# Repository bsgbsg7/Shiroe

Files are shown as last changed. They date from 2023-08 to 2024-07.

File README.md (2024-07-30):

# Design of Electronic Perpetual Calendar Based on ESP32 

## 功能展示

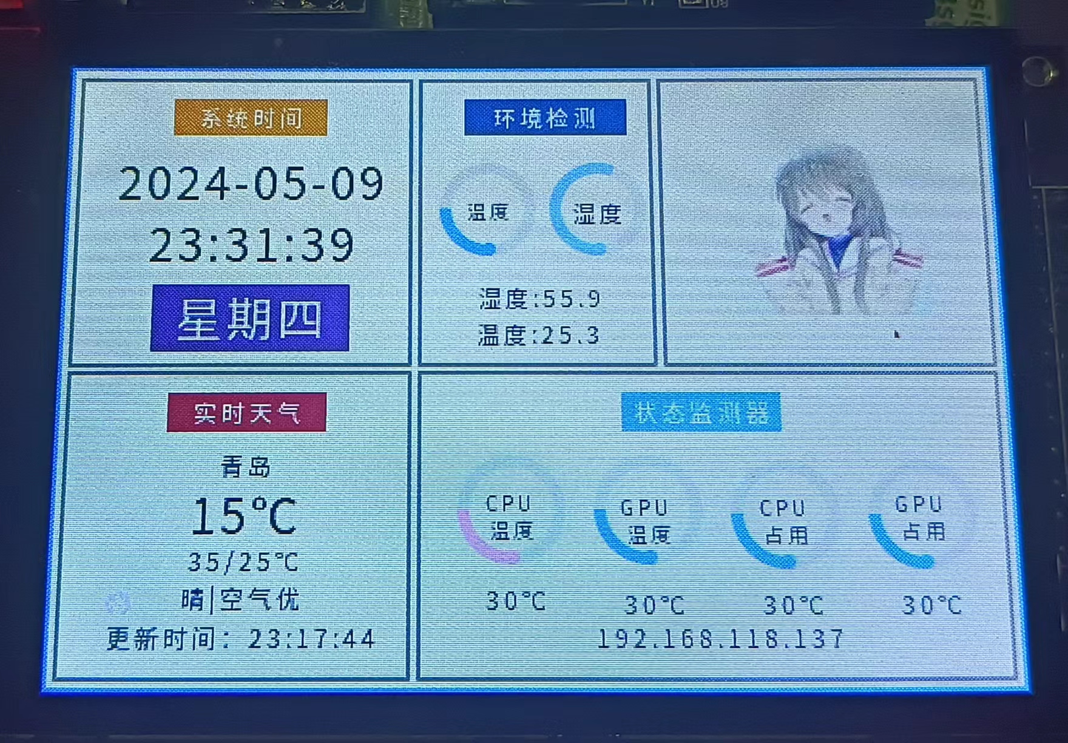
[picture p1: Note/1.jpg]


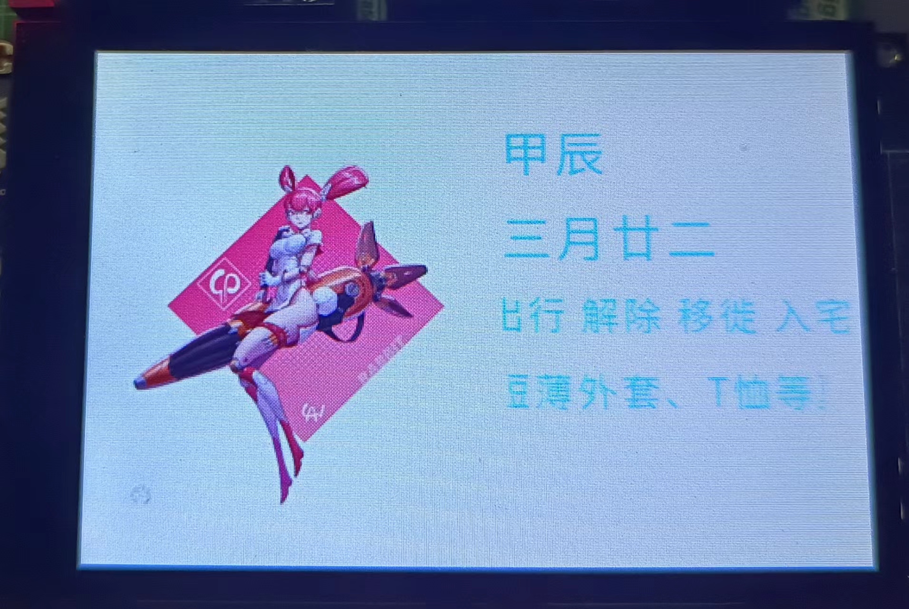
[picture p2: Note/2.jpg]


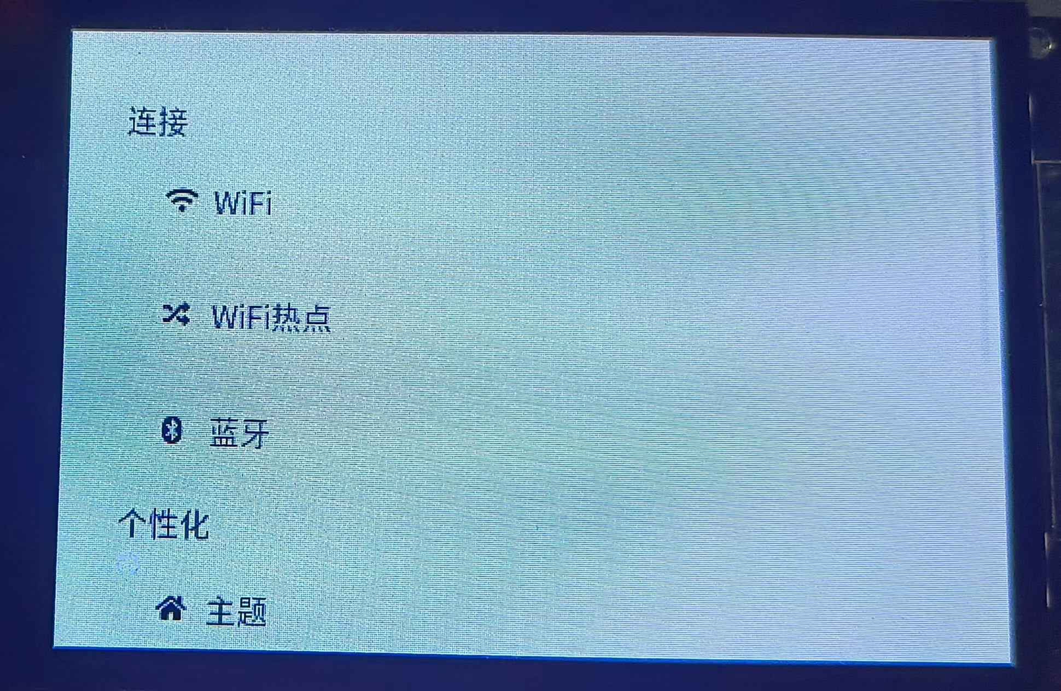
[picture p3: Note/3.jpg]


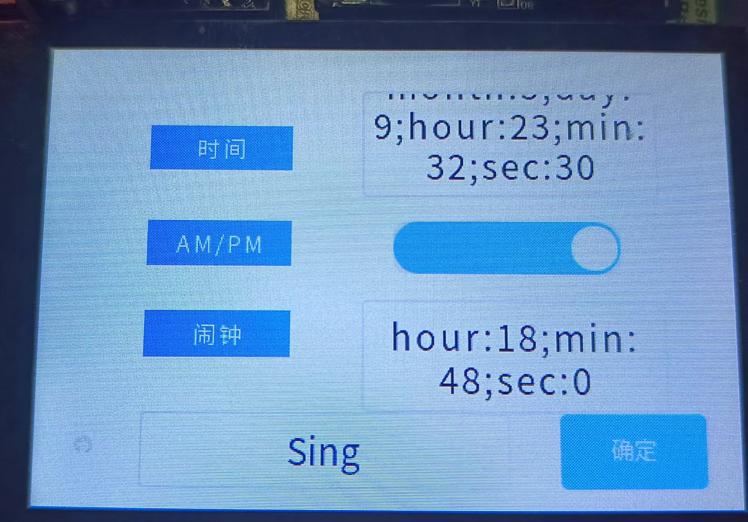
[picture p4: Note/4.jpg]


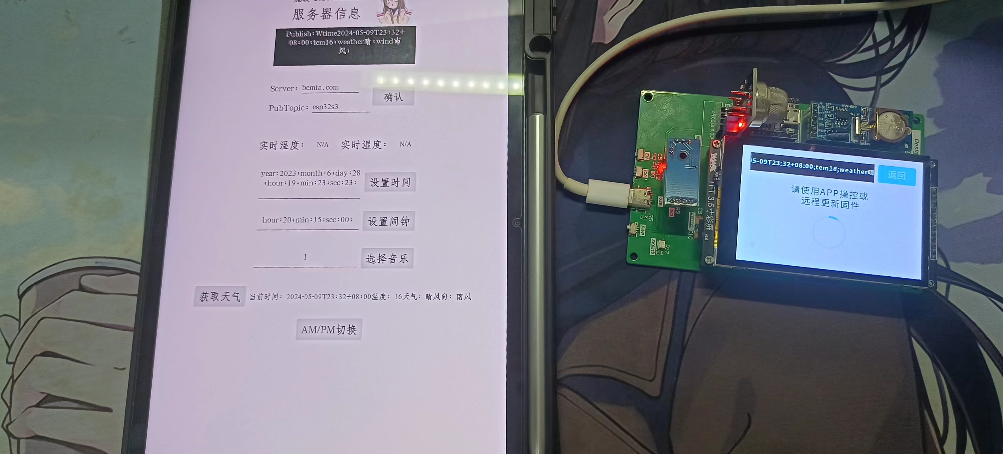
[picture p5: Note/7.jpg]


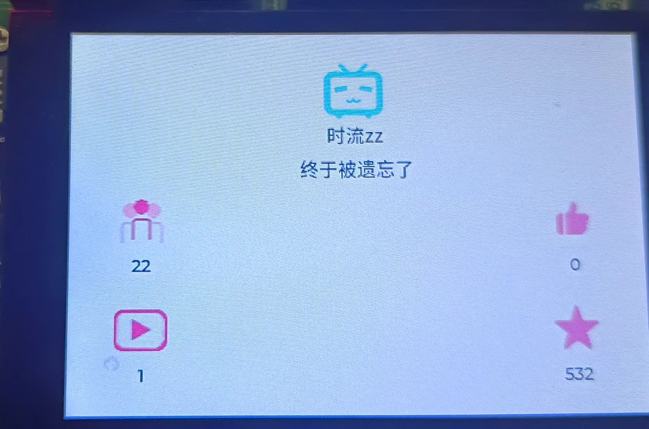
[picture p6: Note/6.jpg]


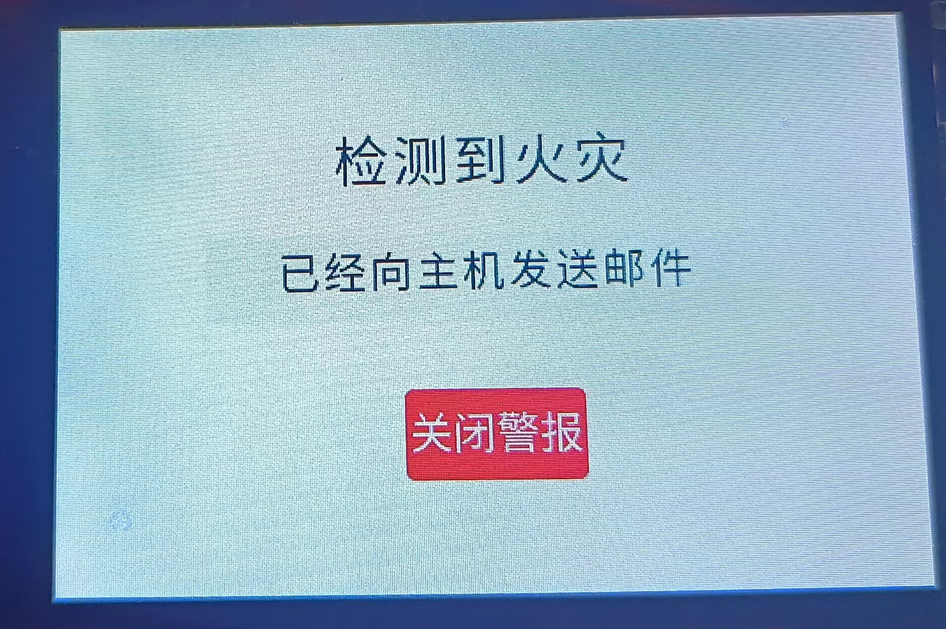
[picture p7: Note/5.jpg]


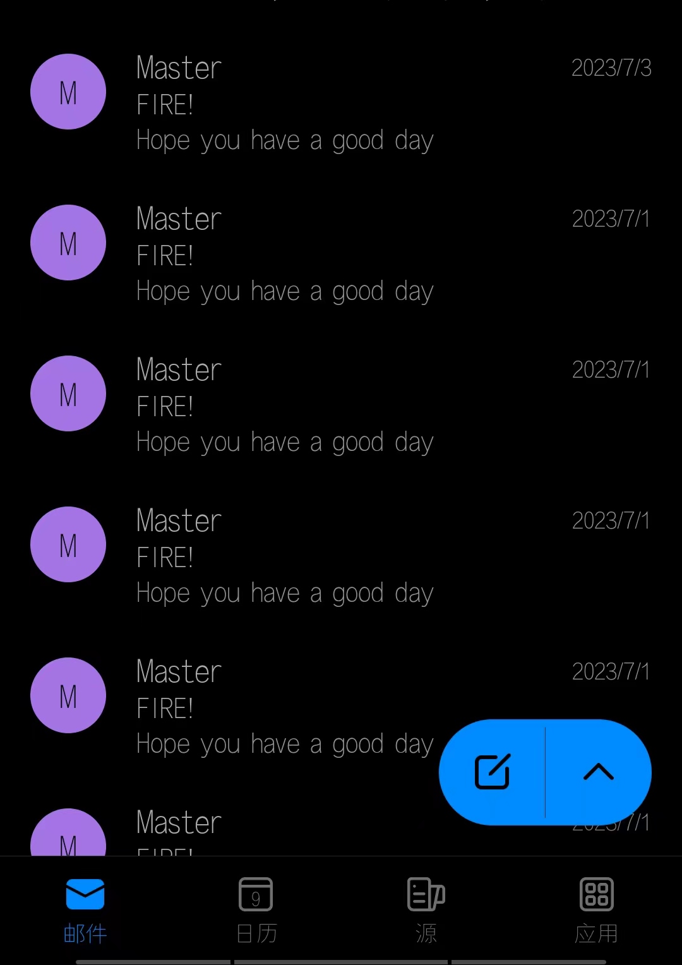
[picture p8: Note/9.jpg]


## 一、已实现的功能

>- 当前的年、月、日、时、分、秒显示
>- 设置年、月、日、时、分、秒
>- AM、 PM 设置与显示
>- 农历年月日、二十四节气显示
>- 闹钟时间设置，闹钟时间到进行声光报警提示
>- 温湿度检测与显示
>- 闹钟音乐选择（采用 TF 卡或录音芯片存储音乐数据）
>- 手机通过蓝牙或 WiFi 网络连接该万年历，通过手机 APP 可以完成基本功能中的所有设置功能
>- 通过编写 Android 手机程序获得网上天气预报数据，并将该数据通过蓝牙或WiFi 网络传递给音乐万年历，万年历可以完成天气信息显示
>- 火灾检测与报警，采用声光报警和发送邮件的形式提醒
>- 电脑状态监测，实时监控电脑CPU、GPU状态
>- Bilibili用户数据实时显示
>- 系统菜单界面

## 二、 硬件设计

### （1）原理图设计及其各模块简介

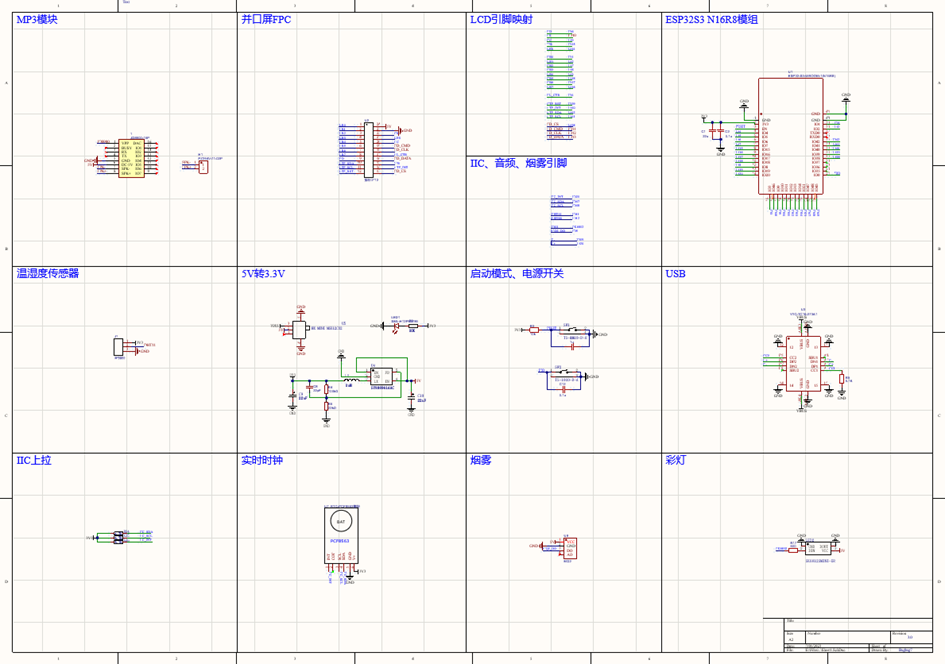
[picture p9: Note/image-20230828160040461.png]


**主控：** ESP32-S3-WROOM-1(N16R8)模组，内置2.4GHz WiFi以及低功耗蓝牙，双核 32 位 LX7 微处理器，高达 240 MHz 的时钟频率， 384 KB ROM ，512 KB SRAM ，16MB Flash，8MB PSRAM。

**电源转换：**SY8089A1AAC同步降压DC/DC稳压器，能够提供高达2A的输出电流，可以在2.5V到5.5V的宽输入电压范围内工作，输出电压纹波小，外接电感小。

**显示屏：**ST7789V电容触摸屏，采用8位并口模式通信。

**时钟芯片：** PCF8563模块，支持IIC通信，配有CR1220备用电池以及二极管保证任何时候都有一个供电。

**烟雾检测模块：**MQ2模块。

**音乐模块：**JQ8900模块，采用特有的一线控制模式，5V供电，通过导线外接8W 0.5Ω的喇叭。

**温湿度模块：**DHT11模块。

**彩灯：**SK6812RGB彩灯。

**USB**：Type-C USB。

### （2）印制板图设计

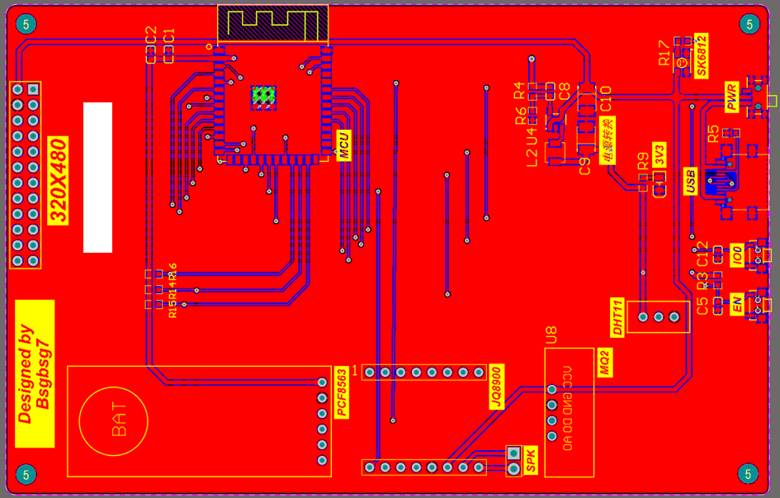
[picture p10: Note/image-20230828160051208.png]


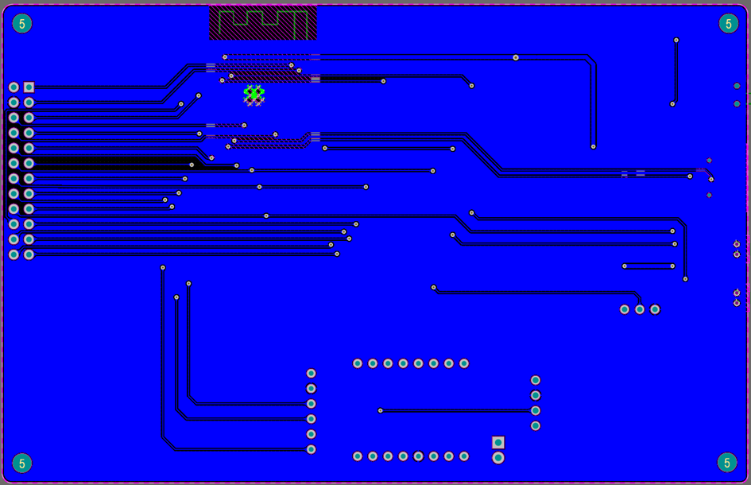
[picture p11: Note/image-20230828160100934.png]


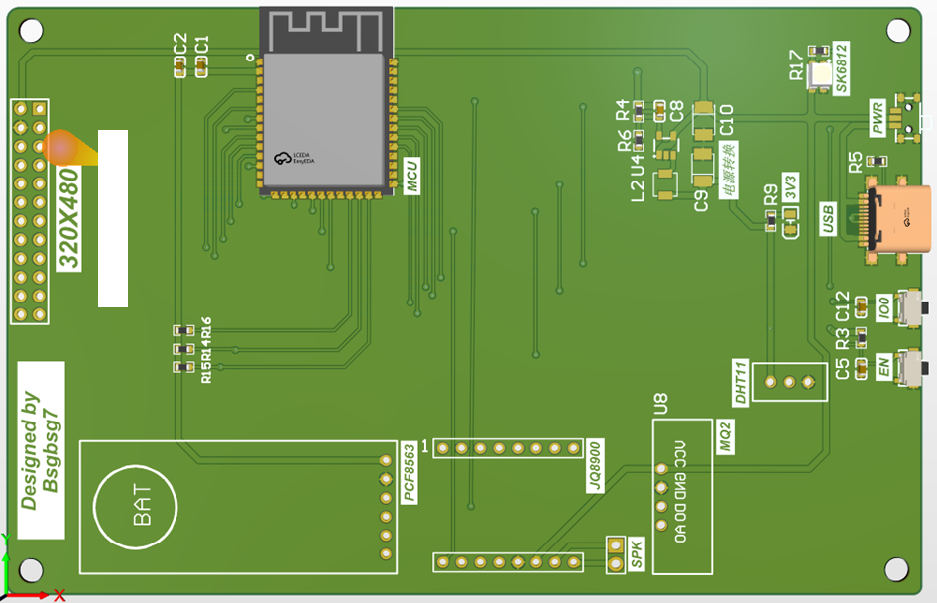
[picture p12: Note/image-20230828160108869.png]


## 三、软件设计

	代码基于Arduino框架，采用LVGL图形库，不同App的页面主要采用GUI Guider软件设计，自动生成代码后移植到工程框架下，页面之间的切换逻辑采用链表连接，根据设定的交互逻辑，自动切换链表指针位置到下一个页面（展开新页面），或回到上一个位置（返回上一个页面）并释放内存。

	其中，各个app页面的设计如下：

	**主页面：**开机初始化联网获取时间并写入pcf8563，通过心知天气api接口获取天气并显示，通过定时器定时读取pcf8563时间，每十分钟获取一次天气，读取dht11数据，获取电脑状态数据，并刷新显示。同时不断检测闹钟和烟雾报警，做出响应。

	**闹钟：**定时器每隔一段时间给jq8900发送指令（发送的时间很短，发送后会自动播放）播放音乐，同时页面添加回调函数检测用户操作（推迟、关闭），返回主页。

	**烟雾警报**：检测到MQ2低电平报警，定时器为jq8900发送音乐播放指令，同时通过smtp协议向手机发送报警邮件。

	**农历：**初始化获取pcf8563时间，通过内置的算法转换为农历日期以及节气、生肖，定时器通过心知天气api获取建议，显示生肖对应的图片。

	**手机App控制：**App采用App Inventor设计，利用巴法云物联网开放平台，使用mqtt协议通信，实时显示订阅收到的时间、闹钟、音乐选择、am/pm设置、天气等信息，并设置。

	**设置：**组件通过全局变量获取数据，保证显示数据为目前的设置情况，添加对应回调函数，用户可以通过点击键盘、开关等操作修改设置，点击确认按钮修改全局变量完成设置。

	**Bilibili**：通过Bilibili开放Api获取用户信息并显示。

## 四、总结

### 1、硬件设计

	一开始电源转换选择不合理，pcb绘制等出现了很多问题，感谢老师的耐心指导和纠正。设计第一版pcb出现了许多问题：

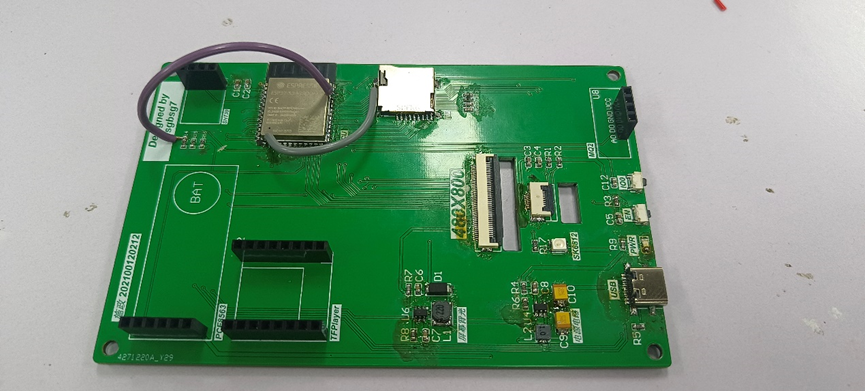
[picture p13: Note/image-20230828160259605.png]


**初版pcb：**

>- FPC排座焊接困难，由于焊接技术不够，fpc出现连锡后刀头怎么都刮不下来。
>- 最开始考虑使用的屏幕过于古老，虽然有开源的基于esp-idf框架的驱动移植代码，但开始高估了自身，完全看不懂此框架下的代码，咨询过后发现重新抑制驱动与lvgl到Arduino框架下过于困难，去掉了屏幕部分，更换为屏幕模块。
>- 芯片无法正常启动，不断重启，在实验室测了一晚上bug，才找到问题。引脚分配不合理，将IO46用于IIC通信，加了上拉电阻，导致芯片无法正常启动（系统启动需要IO46低电平）。

### 2、软件：

1) #### LVGL不会用

	但似乎看着看着，需要用的时候去官网查查就会用了。

2) #### GUI Guider生成代码的移植 

	手动敲ui过于复杂，选择使用恩智浦开发的GUI Guider LVGL页面设计工具，但是网上关于这部分移植并未有太多资料，尝试所有能找到的博客也未能复现，也是忐忐忑忑地摸索了两天才弄清楚怎么移植，才能安心使用LVGL来设计页面。

	具体的移植过程比较复杂，不在此处详细说明，已经发布到我的博客上[《恩智浦 Gui Guider + Platformio + ESP32S3 移植测试》](https://blog.szbsgbsg7.top/2023/05/31/cx-lvgl-4/)。

3) #### UI页面交互逻辑不会设计

	使用LVGL设计页面都完成了，但是不同页面之间如何切换，这个问题困扰了很久，此处感谢[T-Rex1000/DeskAssistant2.0 (github.com)](https://github.com/T-Rex1000/DeskAssistant2.0)的开源代码，

	在细致地学习了此代码中的页面交互逻辑后，仿照完成了此万年历交互的设计，即使用lv_src_load() 函数加载页面，各个app的页面函数中返回lv_obj_t* 类型的页面，再加上“亿点细节”，就可以完成页面切换了。

4) #### 主控触发看门狗重启

	这是此项目中最麻烦的问题，期末时对着不停重启的主控修了两天，一项项排查问题，才找到方法。导致此问题的原因很多，大部分都是指针、地址、内存溢出等导致，此处仅列出几种此项目中遇到的情况及解决方案。

	**不合理的指针使用导致的重启：**

	LVGL涉及非常多的指针，一不注意就可能会出错。可以看到，对于自己创建的指针组合成的结构体，在定时器传递参数时必须转换为指针。而对于LVGL创建的组件，由于本身就是指针，传递时传递本身即可。此处出现问题不会报错，但是会在不正常运行或者重启，一定要谨慎。

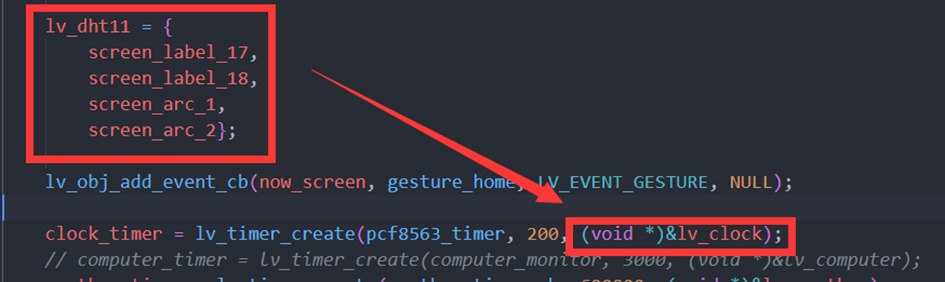
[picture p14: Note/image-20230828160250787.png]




	**定时器导致的重启：**

	LVGL页面切换必须使用lv_timer_del() 函数删除当前页面的所有定时器，否则会导致重启（具体原因暂时未知），因此定时器需要定义为全局变量，在页面切换时非常谨慎、合理地删除或者创建，连接页面交互的链表也要在合适的时候使用free() 释放地址空间。

5) #### 重定义问题

	这个问题最后也不知道是哪里导致的，产生了很多奇奇怪怪的bug，最后代码写在一个文件中才解决，其中一个可能的原因为多个文件中定义，逻辑要清楚，头文件注意不要嵌套调用（实测也不一定是这个导致）。

6) #### 未来改进的方向：

	  此项目代码是在裸机上运行，纯粹的LVGL+定时器，可能会有页面卡死的情况，原开源作者的LVGL页面交互是基于FreeRTOS操作系统的，建议后续上操作系统，应该能够很好地解决这个问题。

	  此项目挖了很多坑，目前仅停留在“能跑”，能作为一个入门硬件几个月的成果，后续有时间会学习并优化硬件和软件。

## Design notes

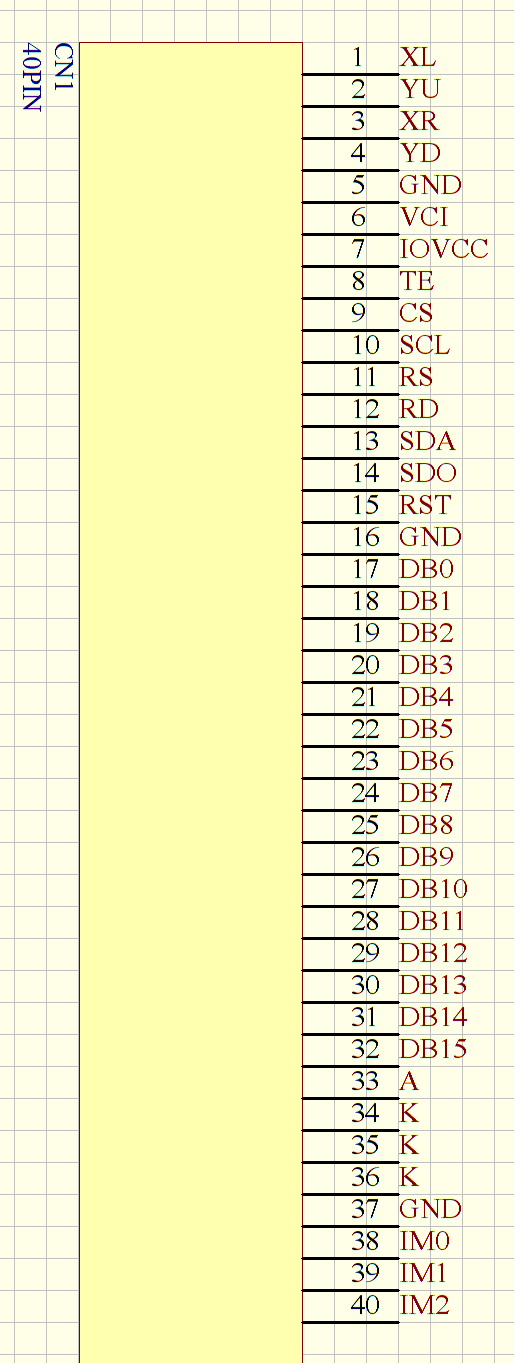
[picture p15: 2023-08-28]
Doc/FPC4301MS-L190-40C-9A全套资料(1)/FPC4301MS-L190-40C-9A全套资料/SPI定义接法1.png

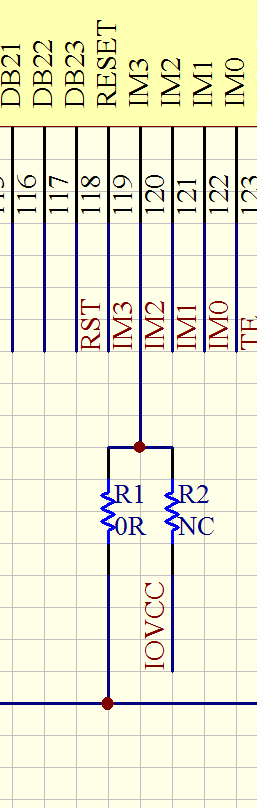
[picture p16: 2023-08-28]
Doc/FPC4301MS-L190-40C-9A全套资料(1)/FPC4301MS-L190-40C-9A全套资料/SPI定义接法2.png

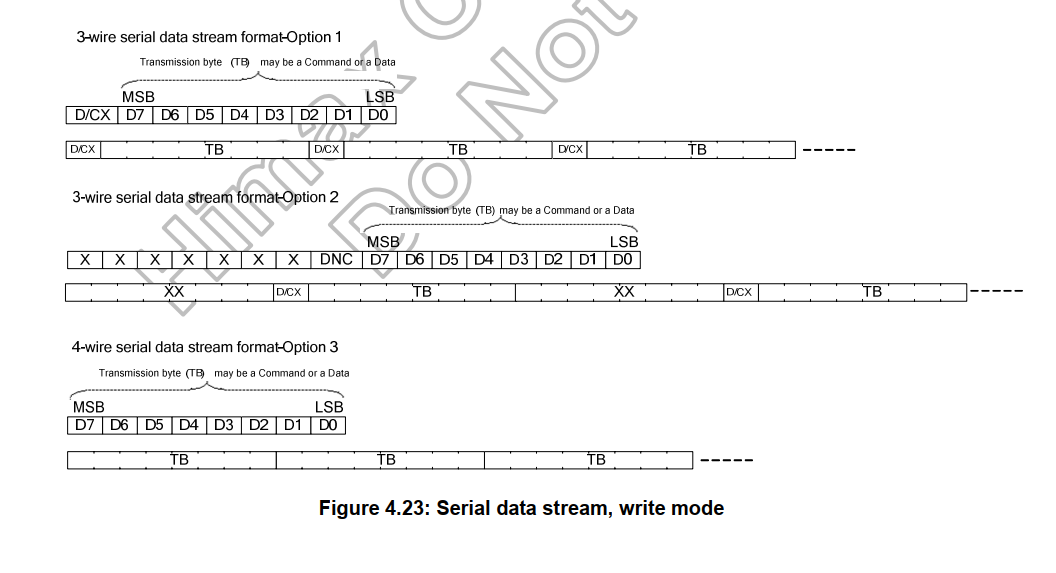
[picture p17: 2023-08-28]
Doc/FPC4301MS-L190-40C-9A全套资料(1)/FPC4301MS-L190-40C-9A全套资料/微信图片_20220726164525.png

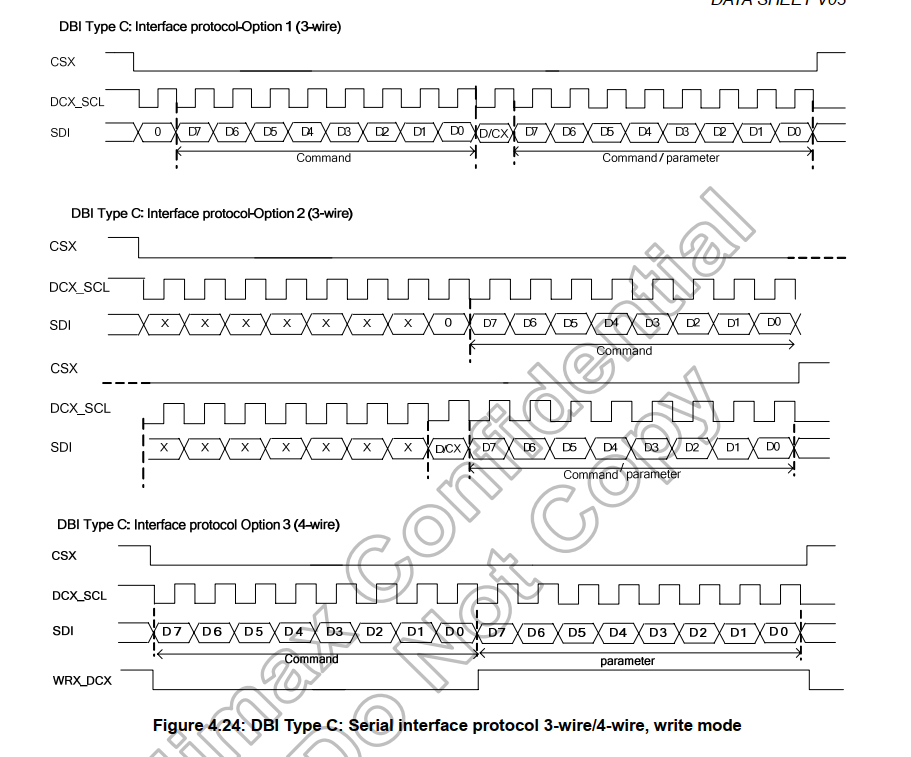
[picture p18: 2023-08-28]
Doc/FPC4301MS-L190-40C-9A全套资料(1)/FPC4301MS-L190-40C-9A全套资料/微信图片_20220726164533.png

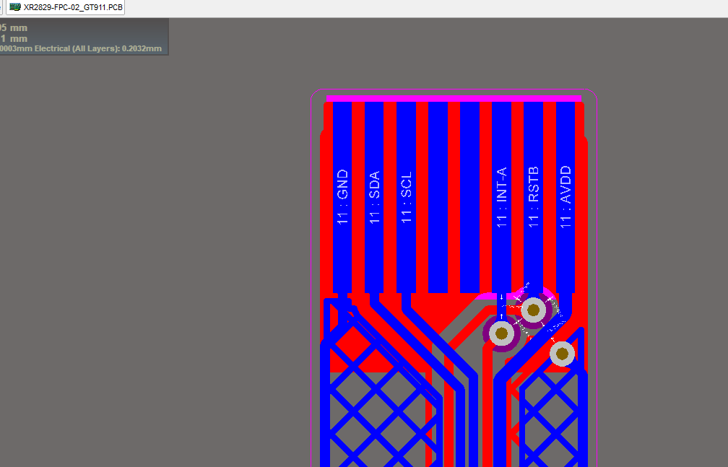
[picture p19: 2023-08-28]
Doc/电容触摸资料(1)/电容触摸资料/ccd84c4491cdf107439712c80b4b56e.png

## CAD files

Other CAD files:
Doc/FPC4301MS-L190-40C-9A全套资料(1)/FPC4301MS-L190-40C-9A全套资料/FPC4301MS-L190-40C-9A外发资料/LCM/C51调试例程/KM200_MCU8bit_FPC4301MS-L190-40C-9A_HX8369A_LG4.3/main.OBJ
Doc/3.50LCD插接40pin-ST7796-电容触摸技术资料/01-规格书与芯片手册/LCM-ZJY350C4001(T).dwg
Doc/FPC4301MS-L190-40C-9A全套资料(1)/FPC4301MS-L190-40C-9A全套资料/FPC4301MS-L190-40C-9A外发资料/LCM/FPC4301MS-L190-40C-9A.dwg
Doc/FPC4301MS-L190-40C-9A全套资料(1)/FPC4301MS-L190-40C-9A全套资料/FPC4301MS-L190-40C-9A外发资料/PCB/PCB4301MS V1.0.dwg
Doc/FPC4301MS-L190-40C-9A全套资料(1)/FPC4301MS-L190-40C-9A全套资料/FPC4301MS-L190-40C-9A外发资料/LCM/C51调试例程/KM200_MCU8bit_FPC4301MS-L190-40C-9A_HX8369A_LG4.3/lcd.obj
Doc/FPC4301MS-L190-40C-9A全套资料(1)/FPC4301MS-L190-40C-9A全套资料/FPC4301MS-L190-40C-9A外发资料/LCM/C51调试例程/KM200_MCU8bit_FPC4301MS-L190-40C-9A_HX8369A_LG4.3/POWER.OBJ

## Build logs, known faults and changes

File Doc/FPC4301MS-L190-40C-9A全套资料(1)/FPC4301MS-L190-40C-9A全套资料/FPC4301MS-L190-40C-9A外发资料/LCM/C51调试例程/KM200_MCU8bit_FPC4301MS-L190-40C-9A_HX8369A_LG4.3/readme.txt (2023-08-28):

/*******************************************************
数据端口定义： 
P2.7  P2.6	P2.5  P2.4  P2.3  P2.2  P2.1  P2.0
DB15  DB14  DB13  DB12  DB11  DB10  DB9   DB8 

P4.7  P4.6	P4.5  P4.4  P4.3  P4.2  P4.1  P4.0
DB7   DB6   DB5   DB4   DB3   DB2   DB1   DB0 

P1.2    P1.3
DB16    DB17
--------------------------------------------------------
控制端口定义：

//MCU | SPI
P0.5     P1.6     P1.7    P3.1   P3.0   
RST      RD0      WR0     RS     CS0	 
         SDA(SDI) SCL(SCK)

//SPI+RGB
P3.4     P1.0      P1.1     P1.2      P1.3
SPI_RS   SPI_CS    SPI_CLK  SPI_DI    SPI_RES

//TP
P1^4	P1^5	  P3^2	  P3^3     P3^4     P3^5	   
TP_CS	TP_DCLK   TP_DIN  TP_DOUT  TP_BUSY  TP_PENIRQ  

//
P0.4  P3.6	    P3.7
TE	  KEY_STEP  KEY

********************************************************/

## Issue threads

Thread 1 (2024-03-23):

学长,可以教教我吗

neverwinHao, 2024-03-23:
学长太刁了太刁了太刁了太刁了太刁了太刁了太刁了太刁了太刁了太刁了太刁了太刁了太刁了太刁了太刁了太刁了太刁了太刁了太刁了太刁了太刁了太刁了太刁了太刁了太刁了太刁了太刁了太刁了太刁了太刁了太刁了太刁了太刁了太刁了太刁了太刁了太刁了太刁了太刁了太刁了太刁了太刁了太刁了太刁了太刁了太刁了太刁了太刁了太刁了太刁了太刁了太刁了太刁了太刁了太刁了太刁了太刁了太刁了太刁了太刁了太刁了太刁了太刁了太刁了太刁了太刁了太刁了太刁了太刁了太刁了太刁了太刁了太刁了太刁了太刁了太刁了太刁了太刁了太刁了学长太刁了太刁了太刁了太刁了太刁了太刁了太刁了太刁了太刁了太刁了太刁了太刁了太刁了太刁了太刁了太刁了太刁了太刁了太刁了太刁了太刁了太刁了太刁了太刁了太刁了太刁了太刁了太刁了太刁了太刁了太刁了太刁了太刁了太刁了太刁了太刁了太刁了太刁了太刁了太刁了太刁了太刁了太刁了太刁了太刁了太刁了太刁了太刁了太刁了太刁了太刁了太刁了太刁了太刁了太刁了太刁了太刁了太刁了太刁了太刁了太刁了太刁了太刁了太刁了太刁了太刁了太刁了太刁了太刁了太刁了太刁了太刁了太刁了太刁了太刁了太刁了太刁了太刁了太刁了学长太刁了太刁了太刁了太刁了太刁了太刁了太刁了太刁了太刁了太刁了太刁了太刁了太刁了太刁了太刁了太刁了太刁了太刁了太刁了太刁了太刁了太刁了太刁了太刁了太刁了太刁了太刁了太刁了太刁了太刁了太刁了太刁了太刁了太刁了太刁了太刁了太刁了太刁了太刁了太刁了太刁了太刁了太刁了太刁了太刁了太刁了太刁了太刁了太刁了太刁了太刁了太刁了太刁了太刁了太刁了太刁了太刁了太刁了太刁了太刁了太刁了太刁了太刁了太刁了太刁了太刁了太刁了太刁了太刁了太刁了太刁了太刁了太刁了太刁了太刁了太刁了太刁了太刁了太刁了学长太刁了太刁了太刁了太刁了太刁了太刁了太刁了太刁了太刁了太刁了太刁了太刁了太刁了太刁了太刁了太刁了太刁了太刁了太刁了太刁了太刁了太刁了太刁了太刁了太刁了太刁了太刁了太刁了太刁了太刁了太刁了太刁了太刁了太刁了太刁了太刁了太刁了太刁了太刁了太刁了太刁了太刁了太刁了太刁了太刁了太刁了太刁了太刁了太刁了太刁了太刁了太刁了太刁了太刁了太刁了太刁了太刁了太刁了太刁了太刁了太刁了太刁了太刁了太刁了太刁了太刁了太刁了太刁了太刁了太刁了太刁了太刁了太刁了太刁了太刁了太刁了太刁了太刁了太刁了学长太刁了太刁了太刁了太刁了太刁了太刁了太刁了太刁了太刁了太刁了太刁了太刁了太刁了太刁了太刁了太刁了太刁了太刁了太刁了太刁了太刁了太刁了太刁了太刁了太刁了太刁了太刁了太刁了太刁了太刁了太刁了太刁了太刁了太刁了太刁了太刁了太刁了太刁了太刁了太刁了太刁了太刁了太刁了太刁了太刁了太刁了太刁了太刁了太刁了太刁了太刁了太刁了太刁了太刁了太刁了太刁了太刁了太刁了太刁了太刁了太刁了太刁了太刁了太刁了太刁了太刁了太刁了太刁了太刁了太刁了太刁了太刁了太刁了太刁了太刁了太刁了太刁了太刁了太刁了学长太刁了太刁了太刁了太刁了太刁了太刁了太刁了太刁了太刁了太刁了太刁了太刁了太刁了太刁了太刁了太刁了太刁了太刁了太刁了太刁了太刁了太刁了太刁了太刁了太刁了太刁了太刁了太刁了太刁了太刁了太刁了太刁了太刁了太刁了太刁了太刁了太刁了太刁了太刁了太刁了太刁了太刁了太刁了太刁了太刁了太刁了太刁了太刁了太刁了太刁了太刁了太刁了太刁了太刁了太刁了太刁了太刁了太刁了太刁了太刁了太刁了太刁了太刁了太刁了太刁了太刁了太刁了太刁了太刁了太刁了太刁了太刁了太刁了太刁了太刁了太刁了太刁了太刁了太刁了学长太刁了太刁了太刁了太刁了太刁了太刁了太刁了太刁了太刁了太刁了太刁了太刁了太刁了太刁了太刁了太刁了太刁了太刁了太刁了太刁了太刁了太刁了太刁了太刁了太刁了太刁了太刁了太刁了太刁了太刁了太刁了太刁了太刁了太刁了太刁了太刁了太刁了太刁了太刁了太刁了太刁了太刁了太刁了太刁了太刁了太刁了太刁了太刁了太刁了太刁了太刁了太刁了太刁了太刁了太刁了太刁了太刁了太刁了太刁了太刁了太刁了太刁了太刁了太刁了太刁了太刁了太刁了太刁了太刁了太刁了太刁了太刁了太刁了太刁了太刁了太刁了太刁了太刁了太刁了学长太刁了太刁了太刁了太刁了太刁了太刁了太刁了太刁了太刁了太刁了太刁了太刁了太刁了太刁了太刁了太刁了太刁了太刁了太刁了太刁了太刁了太刁了太刁了太刁了太刁了太刁了太刁了太刁了太刁了太刁了太刁了太刁了太刁了太刁了太刁了太刁了太刁了太刁了太刁了太刁了太刁了太刁了太刁了太刁了太刁了太刁了太刁了太刁了太刁了太刁了太刁了太刁了太刁了太刁了太刁了太刁了太刁了太刁了太刁了太刁了太刁了太刁了太刁了太刁了太刁了太刁了太刁了太刁了太刁了太刁了太刁了太刁了太刁了太刁了太刁了太刁了太刁了太刁了太刁了学长太刁了太刁了太刁了太刁了太刁了太刁了太刁了太刁了太刁了太刁了太刁了太刁了太刁了太刁了太刁了太刁了太刁了太刁了太刁了太刁了太刁了太刁了太刁了太刁了太刁了太刁了太刁了太刁了太刁了太刁了太刁了太刁了太刁了太刁了太刁了太刁了太刁了太刁了太刁了太刁了太刁了太刁了太刁了太刁了太刁了太刁了太刁了太刁了太刁了太刁了太刁了太刁了太刁了太刁了太刁了太刁了太刁了太刁了太刁了太刁了太刁了太刁了太刁了太刁了太刁了太刁了太刁了太刁了太刁了太刁了太刁了太刁了太刁了太刁了太刁了太刁了太刁了太刁了太刁了学长太刁了太刁了太刁了太刁了太刁了太刁了太刁了太刁了太刁了太刁了太刁了太刁了太刁了太刁了太刁了太刁了太刁了太刁了太刁了太刁了太刁了太刁了太刁了太刁了太刁了太刁了太刁了太刁了太刁了太刁了太刁了太刁了太刁了太刁了太刁了太刁了太刁了太刁了太刁了太刁了太刁了太刁了太刁了太刁了太刁了太刁了太刁了太刁了太刁了太刁了太刁了太刁了太刁了太刁了太刁了太刁了太刁了太刁了太刁了太刁了太刁了太刁了太刁了太刁了太刁了太刁了太刁了太刁了太刁了太刁了太刁了太刁了太刁了太刁了太刁了太刁了太刁了太刁了太刁了学长太刁了太刁了太刁了太刁了太刁了太刁了太刁了太刁了太刁了太刁了太刁了太刁了太刁了太刁了太刁了太刁了太刁了太刁了太刁了太刁了太刁了太刁了太刁了太刁了太刁了太刁了太刁了太刁了太刁了太刁了太刁了太刁了太刁了太刁了太刁了太刁了太刁了太刁了太刁了太刁了太刁了太刁了太刁了太刁了太刁了太刁了太刁了太刁了太刁了太刁了太刁了太刁了太刁了太刁了太刁了太刁了太刁了太刁了太刁了太刁了太刁了太刁了太刁了太刁了太刁了太刁了太刁了太刁了太刁了太刁了太刁了太刁了太刁了太刁了太刁了太刁了太刁了太刁了太刁了学长太刁了太刁了太刁了太刁了太刁了太刁了太刁了太刁了太刁了太刁了太刁了太刁了太刁了太刁了太刁了太刁了太刁了太刁了太刁了太刁了太刁了太刁了太刁了太刁了太刁了太刁了太刁了太刁了太刁了太刁了太刁了太刁了太刁了太刁了太刁了太刁了太刁了太刁了太刁了太刁了太刁了太刁了太刁了太刁了太刁了太刁了太刁了太刁了太刁了太刁了太刁了太刁了太刁了太刁了太刁了太刁了太刁了太刁了太刁了太刁了太刁了太刁了太刁了太刁了太刁了太刁了太刁了太刁了太刁了太刁了太刁了太刁了太刁了太刁了太刁了太刁了太刁了太刁了太刁了学长太刁了太刁了太刁了太刁了太刁了太刁了太刁了太刁了太刁了太刁了太刁了太刁了太刁了太刁了太刁了太刁了太刁了太刁了太刁了太刁了太刁了太刁了太刁了太刁了太刁了太刁了太刁了太刁了太刁了太刁了太刁了太刁了太刁了太刁了太刁了太刁了太刁了太刁了太刁了太刁了太刁了太刁了太刁了太刁了太刁了太刁了太刁了太刁了太刁了太刁了太刁了太刁了太刁了太刁了太刁了太刁了太刁了太刁了太刁了太刁了太刁了太刁了太刁了太刁了太刁了太刁了太刁了太刁了太刁了太刁了太刁了太刁了太刁了太刁了太刁了太刁了太刁了太刁了太刁了学长太刁了太刁了太刁了太刁了太刁了太刁了太刁了太刁了太刁了太刁了太刁了太刁了太刁了太刁了太刁了太刁了太刁了太刁了太刁了太刁了太刁了太刁了太刁了太刁了太刁了太刁了太刁了太刁了太刁了太刁了太刁了太刁了太刁了太刁了太刁了太刁了太刁了太刁了太刁了太刁了太刁了太刁了太刁了太刁了太刁了太刁了太刁了太刁了太刁了太刁了太刁了太刁了太刁了太刁了太刁了太刁了太刁了太刁了太刁了太刁了太刁了太刁了太刁了太刁了太刁了太刁了太刁了太刁了太刁了太刁了太刁了太刁了太刁了太刁了太刁了太刁了太刁了太刁了太刁了学长太刁了太刁了太刁了太刁了太刁了太刁了太刁了太刁了太刁了太刁了太刁了太刁了太刁了太刁了太刁了太刁了太刁了太刁了太刁了太刁了太刁了太刁了太刁了太刁了太刁了太刁了太刁了太刁了太刁了太刁了太刁了太刁了太刁了太刁了太刁了太刁了太刁了太刁了太刁了太刁了太刁了太刁了太刁了太刁了太刁了太刁了太刁了太刁了太刁了太刁了太刁了太刁了太刁了太刁了太刁了太刁了太刁了太刁了太刁了太刁了太刁了太刁了太刁了太刁了太刁了太刁了太刁了太刁了太刁了太刁了太刁了太刁了太刁了太刁了太刁了太刁了太刁了太刁了太刁了学长太刁了太刁了太刁了太刁了太刁了太刁了太刁了太刁了太刁了太刁了太刁了太刁了太刁了太刁了太刁了太刁了太刁了太刁了太刁了太刁了太刁了太刁了太刁了太刁了太刁了太刁了太刁了太刁了太刁了太刁了太刁了太刁了太刁了太刁了太刁了太刁了太刁了太刁了太刁了太刁了太刁了太刁了太刁了太刁了太刁了太刁了太刁了太刁了太刁了太刁了太刁了太刁了太刁了太刁了太刁了太刁了太刁了太刁了太刁了太刁了太刁了太刁了太刁了太刁了太刁了太刁了太刁了太刁了太刁了太刁了太刁了太刁了太刁了太刁了太刁了太刁了太刁了太刁了太刁了学长太刁了太刁了太刁了太刁了太刁了太刁了太刁了太刁了太刁了太刁了太刁了太刁了太刁了太刁了太刁了太刁了太刁了太刁了太刁了太刁了太刁了太刁了太刁了太刁了太刁了太刁了太刁了太刁了太刁了太刁了太刁了太刁了太刁了太刁了太刁了太刁了太刁了太刁了太刁了太刁了太刁了太刁了太刁了太刁了太刁了太刁了太刁了太刁了太刁了太刁了太刁了太刁了太刁了太刁了太刁了太刁了太刁了太刁了太刁了太刁了太刁了太刁了太刁了太刁了太刁了太刁了太刁了太刁了太刁了太刁了太刁了太刁了太刁了太刁了太刁了太刁了太刁了太刁了太刁了学长太刁了太刁了太刁了太刁了太刁了太刁了太刁了太刁了太刁了太刁了太刁了太刁了太刁了太刁了太刁了太刁了太刁了太刁了太刁了太刁了太刁了太刁了太刁了太刁了太刁了太刁了太刁了太刁了太刁了太刁了太刁了太刁了太刁了太刁了太刁了太刁了太刁了太刁了太刁了太刁了太刁了太刁了太刁了太刁了太刁了太刁了太刁了太刁了太刁了太刁了太刁了太刁了太刁了太刁了太刁了太刁了太刁了太刁了太刁了太刁了太刁了太刁了太刁了太刁了太刁了太刁了太刁了太刁了太刁了太刁了太刁了太刁了太刁了太刁了太刁了太刁了太刁了太刁了太刁了学长太刁了太刁了太刁了太刁了太刁了太刁了太刁了太刁了太刁了太刁了太刁了太刁了太刁了太刁了太刁了太刁了太刁了太刁了太刁了太刁了太刁了太刁了太刁了太刁了太刁了太刁了太刁了太刁了太刁了太刁了太刁了太刁了太刁了太刁了太刁了太刁了太刁了太刁了太刁了太刁了太刁了太刁了太刁了太刁了太刁了太刁了太刁了太刁了太刁了太刁了太刁了太刁了太刁了太刁了太刁了太刁了太刁了太刁了太刁了太刁了太刁了太刁了太刁了太刁了太刁了太刁了太刁了太刁了太刁了太刁了太刁了太刁了太刁了太刁了太刁了太刁了太刁了太刁了太刁了学长太刁了太刁了太刁了太刁了太刁了太刁了太刁了太刁了太刁了太刁了太刁了太刁了太刁了太刁了太刁了太刁了太刁了太刁了太刁了太刁了太刁了太刁了太刁了太刁了太刁了太刁了太刁了太刁了太刁了太刁了太刁了太刁了太刁了太刁了太刁了太刁了太刁了太刁了太刁了太刁了太刁了太刁了太刁了太刁了太刁了太刁了太刁了太刁了太刁了太刁了太刁了太刁了太刁了太刁了太刁了太刁了太刁了太刁了太刁了太刁了太刁了太刁了太刁了太刁了太刁了太刁了太刁了太刁了太刁了太刁了太刁了太刁了太刁了太刁了太刁了太刁了太刁了太刁了太刁了学长太刁了太刁了太刁了太刁了太刁了太刁了太刁了太刁了太刁了太刁了太刁了太刁了太刁了太刁了太刁了太刁了太刁了太刁了太刁了太刁了太刁了太刁了太刁了太刁了太刁了太刁了太刁了太刁了太刁了太刁了太刁了太刁了太刁了太刁了太刁了太刁了太刁了太刁了太刁了太刁了太刁了太刁了太刁了太刁了太刁了太刁了太刁了太刁了太刁了太刁了太刁了太刁了太刁了太刁了太刁了太刁了太刁了太刁了太刁了太刁了太刁了太刁了太刁了太刁了太刁了太刁了太刁了太刁了太刁了太刁了太刁了太刁了太刁了太刁了太刁了太刁了太刁了太刁了太刁了学长太刁了太刁了太刁了太刁了太刁了太刁了太刁了太刁了太刁了太刁了太刁了太刁了太刁了太刁了太刁了太刁了太刁了太刁了太刁了太刁了太刁了太刁了太刁了太刁了太刁了太刁了太刁了太刁了太刁了太刁了太刁了太刁了太刁了太刁了太刁了太刁了太刁了太刁了太刁了太刁了太刁了太刁了太刁了太刁了太刁了太刁了太刁了太刁了太刁了太刁了太刁了太刁了太刁了太刁了太刁了太刁了太刁了太刁了太刁了太刁了太刁了太刁了太刁了太刁了太刁了太刁了太刁了太刁了太刁了太刁了太刁了太刁了太刁了太刁了太刁了太刁了太刁了太刁了太刁了学长太刁了太刁了太刁了太刁了太刁了太刁了太刁了太刁了太刁了太刁了太刁了太刁了太刁了太刁了太刁了太刁了太刁了太刁了太刁了太刁了太刁了太刁了太刁了太刁了太刁了太刁了太刁了太刁了太刁了太刁了太刁了太刁了太刁了太刁了太刁了太刁了太刁了太刁了太刁了太刁了太刁了太刁了太刁了太刁了太刁了太刁了太刁了太刁了太刁了太刁了太刁了太刁了太刁了太刁了太刁了太刁了太刁了太刁了太刁了太刁了太刁了太刁了太刁了太刁了太刁了太刁了太刁了太刁了太刁了太刁了太刁了太刁了太刁了太刁了太刁了太刁了太刁了太刁了太刁了学长太刁了太刁了太刁了太刁了太刁了太刁了太刁了太刁了太刁了太刁了太刁了太刁了太刁了太刁了太刁了太刁了太刁了太刁了太刁了太刁了太刁了太刁了太刁了太刁了太刁了太刁了太刁了太刁了太刁了太刁了太刁了太刁了太刁了太刁了太刁了太刁了太刁了太刁了太刁了太刁了太刁了太刁了太刁了太刁了太刁了太刁了太刁了太刁了太刁了太刁了太刁了太刁了太刁了太刁了太刁了太刁了太刁了太刁了太刁了太刁了太刁了太刁了太刁了太刁了太刁了太刁了太刁了太刁了太刁了太刁了太刁了太刁了太刁了太刁了太刁了太刁了太刁了太刁了太刁了学长太刁了太刁了太刁了太刁了太刁了太刁了太刁了太刁了太刁了太刁了太刁了太刁了太刁了太刁了太刁了太刁了太刁了太刁了太刁了太刁了太刁了太刁了太刁了太刁了太刁了太刁了太刁了太刁了太刁了太刁了太刁了太刁了太刁了太刁了太刁了太刁了太刁了太刁了太刁了太刁了太刁了太刁了太刁了太刁了太刁了太刁了太刁了太刁了太刁了太刁了太刁了太刁了太刁了太刁了太刁了太刁了太刁了太刁了太刁了太刁了太刁了太刁了太刁了太刁了太刁了太刁了太刁了太刁了太刁了太刁了太刁了太刁了太刁了太刁了太刁了太刁了太刁了太刁了太刁了学长太刁了太刁了太刁了太刁了太刁了太刁了太刁了太刁了太刁了太刁了太刁了太刁了太刁了太刁了太刁了太刁了太刁了太刁了太刁了太刁了太刁了太刁了太刁了太刁了太刁了太刁了太刁了太刁了太刁了太刁了太刁了太刁了太刁了太刁了太刁了太刁了太刁了太刁了太刁了太刁了太刁了太刁了太刁了太刁了太刁了太刁了太刁了太刁了太刁了太刁了太刁了太刁了太刁了太刁了太刁了太刁了太刁了太刁了太刁了太刁了太刁了太刁了太刁了太刁了太刁了太刁了太刁了太刁了太刁了太刁了太刁了太刁了太刁了太刁了太刁了太刁了太刁了太刁了太刁了学长太刁了太刁了太刁了太刁了太刁了太刁了太刁了太刁了太刁了太刁了太刁了太刁了太刁了太刁了太刁了太刁了太刁了太刁了太刁了太刁了太刁了太刁了太刁了太刁了太刁了太刁了太刁了太刁了太刁了太刁了太刁了太刁了太刁了太刁了太刁了太刁了太刁了太刁了太刁了太刁了太刁了太刁了太刁了太刁了太刁了太刁了太刁了太刁了太刁了太刁了太刁了太刁了太刁了太刁了太刁了太刁了太刁了太刁了太刁了太刁了太刁了太刁了太刁了太刁了太刁了太刁了太刁了太刁了太刁了太刁了太刁了太刁了太刁了太刁了太刁了太刁了太刁了太刁了太刁了学长太刁了太刁了太刁了太刁了太刁了太刁了太刁了太刁了太刁了太刁了太刁了太刁了太刁了太刁了太刁了太刁了太刁了太刁了太刁了太刁了太刁了太刁了太刁了太刁了太刁了太刁了太刁了太刁了太刁了太刁了太刁了太刁了太刁了太刁了太刁了太刁了太刁了太刁了太刁了太刁了太刁了太刁了太刁了太刁了太刁了太刁了太刁了太刁了太刁了太刁了太刁了太刁了太刁了太刁了太刁了太刁了太刁了太刁了太刁了太刁了太刁了太刁了太刁了太刁了太刁了太刁了太刁了太刁了太刁了太刁了太刁了太刁了太刁了太刁了太刁了太刁了太刁了太刁了太刁了学长太刁了太刁了太刁了太刁了太刁了太刁了太刁了太刁了太刁了太刁了太刁了太刁了太刁了太刁了太刁了太刁了太刁了太刁了太刁了太刁了太刁了太刁了太刁了太刁了太刁了太刁了太刁了太刁了太刁了太刁了太刁了太刁了太刁了太刁了太刁了太刁了太刁了太刁了太刁了太刁了太刁了太刁了太刁了太刁了太刁了太刁了太刁了太刁了太刁了太刁了太刁了太刁了太刁了太刁了太刁了太刁了太刁了太刁了太刁了太刁了太刁了太刁了太刁了太刁了太刁了太刁了太刁了太刁了太刁了太刁了太刁了太刁了太刁了太刁了太刁了太刁了太刁了太刁了太刁了

Closed 2024-03-25.

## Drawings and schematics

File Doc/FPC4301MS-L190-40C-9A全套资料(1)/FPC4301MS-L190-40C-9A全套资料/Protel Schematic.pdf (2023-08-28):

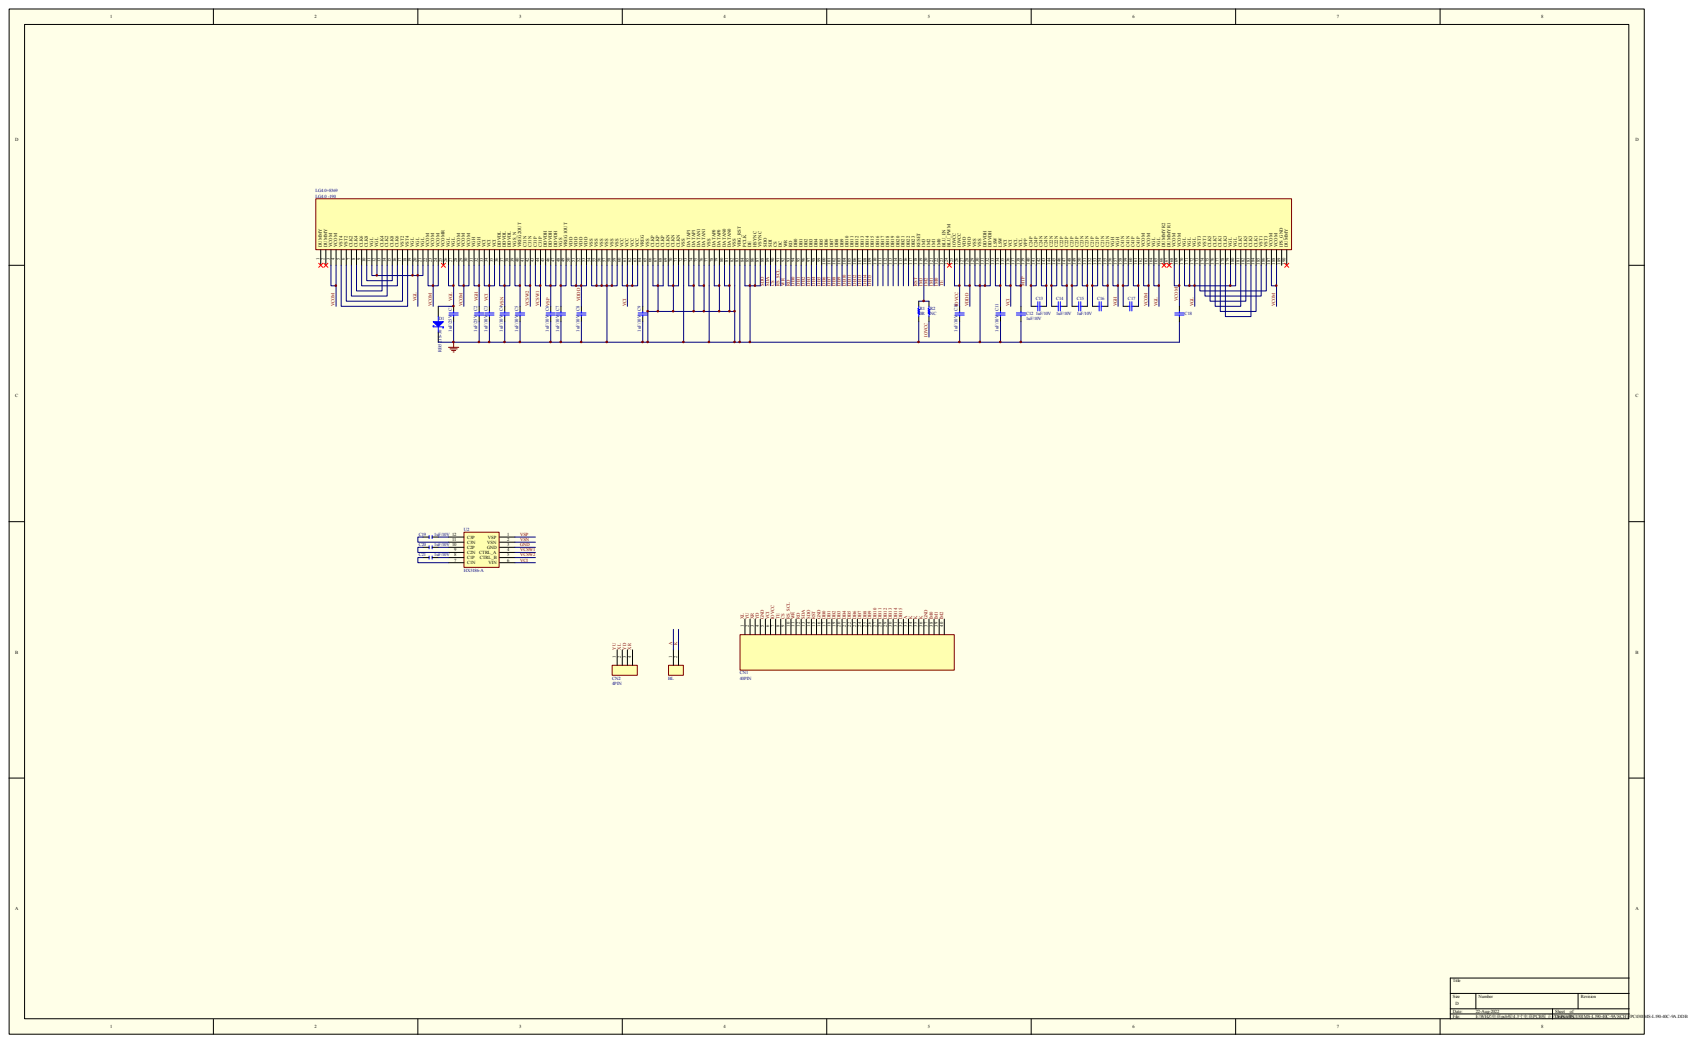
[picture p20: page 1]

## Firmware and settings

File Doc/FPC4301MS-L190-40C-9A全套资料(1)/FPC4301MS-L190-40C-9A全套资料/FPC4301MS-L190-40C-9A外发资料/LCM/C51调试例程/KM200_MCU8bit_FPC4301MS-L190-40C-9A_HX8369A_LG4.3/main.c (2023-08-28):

#include "c8051F340.h"
#include <intrins.h>
#include <absacc.h>
#include <stdlib.h>
#include <main.h>
#include <lcd\lcd.h>
#include <POWER.h>
#include "oledfont.h"  	

	unsigned char vcom;
	unsigned char POWER_VOL=1,PCH=10,at_jump=1; 
/********************************************************************************/
void main(void)
{ 
	

    unsigned char key;
		MCU_Init();
		OLED_Init();//初始化OLED  
		OLED_Clear(); 
		Disp_Pro_Name();

	while(1)
			{
						key=KEY_Scan();

						if(key==KEY2_PRES)
								{	
									FM_short();
									if(PCH==10) PCH=18; 								
									PCH--;
									lcd_show(PCH);
									at_jump=0;		

								}

						if(key==KEY3_PRES)
								{	
											if( vcom_adj==1)
											{								
														FM_short();		
														vcom+=vcom_Step;
														VCOM_ADJ_();	
											}
											
													if( vcom_adj==0)	
													{									
															FM_short();
															PCH++;								
															if(PCH==18) PCH=10; 
															lcd_show(PCH);
															at_jump=0;
													}
											
								}
								
						if(key==KEY1_PRES)
								{
											switch(POWER_VOL)
											{
												case 0: Power_off(); break;
												case 1: Power_on(); at_jump=1;  break;												
												default: break;
										}

									}
								
													if(POWER_VOL==0&&at_jump==1&&AUTO_PIC)		
											{
													
														lcd_show(PCH);	
												
												
												
											#ifdef READ_REG
														Disp_ID_Lcd();
												#endif
												
												
												
														PCH++;
														TEST_IMG();
														if(PCH==18) PCH=10;
											}

			}		
}

//----------------------------------------------------------------------
void Delay(unsigned int dly)
{
    unsigned int i,j,k;
	
	  for(i=0;i<dly;i++)
	{
  for(k=0;k<5;k++)
    	for(j=0;j<959;j++);
	}
}


void  MCU_Init(void)
{
    unsigned char n;
	PCA0MD &= ~0x40;

			//OSC
			OSCICN = 0x83; 	  //Internal oscillator enabled, SYSCLK = Internal Oscillator = 12MHz
			CLKMUL = 0x00;    //Select internal oscillator as clock multiplier source clock

			CLKMUL |= 0x80;   //Enable clock multiplier

			for(n=0;n<255;n++);

			CLKMUL |= 0xC0;           //Initialize the clock multiplier
			while(!(CLKMUL & 0x20));  //Wait for multiplier to lock
			CLKSEL = 0x00;            //Change SYSCLK to (4x Multiplier    ) = 48MHz  (48MHz is as fast as F34 will run); 0x03;
			RSTSRC   |= 0x02;  

	
	FLSCL = FLSCL | 0x90;
CLKSEL = CLKSEL | 0x03;
OSCICN = OSCICN | 0x03;

//  P0~P4					 //set high impedance ,	skipped by crossbar
//	P0MDIN |= 0xFF;          //数字输入(无模拟输入）
//	P0MDOUT = 0x00; 	 P0 |= 0XFF;      //P0口 置1  
//	P1MDOUT = 0x00;	   P1 |= 0XFF;      //P0口 置1  


	P0MDOUT |= 0xFF;	
	P1MDOUT |= 0xFF;	
	P2MDOUT |= 0xFF;
	P3MDOUT |= 0xFF;	
//	P4MDIN  |= 0xFF;    //数字输入(无模拟输入）
	
	
	P4MDOUT = 0x00;	 //Set Input Mode Before Read 
	P4MDIN  |= 0xFF; 
	
	

	

	 
//		XBR0     |= 0x02;	
			XBR1     |= 0x40;       // Enable Crossbar
			
	IOVCC_EN = 0;
		VCI_EN = 0;
		 BL_EN = 0;
		MTP_EN = 0;							
FM_Long();

#ifdef SPI_4W
	XBR0     |= 0x02;	
	XBR1     |= 0x40;       // Enable Crossbar
	CLKSEL = 0x03;
	SPI0CFG   = 0x70;
	SPI0CN    = 0x0f;
	//SPI0CKR   = (48000000/(2*400000)) - 1;  
	SPI0CKR=0x00;
#endif	
Power_off();
}



void FM_short(void)
{
			FMQ=1;
			Delay(10);	
			FMQ=0;	
}

void FM_Long(void)
{
			FMQ=1;
			Delay(200);	
			FMQ=0;	
}

unsigned char KEY_Scan(void)
{	 
	unsigned char KEY_NUM;  
	static u8 key_up=1;//按键按松开标志
			KEY_NUM=P4;
	if((!((KEY_NUM&0xe0)==0xe0))&&key_up)
	{
				KEY_NUM|=0xE0;
				Delay(15);//去抖动 
						
					KEY_NUM=P4;
			if(!((KEY_NUM&0xe0)==0xe0))
			{	   
				
					key_up=0;
	
			     if((KEY_NUM&0x80)==0)return KEY1_PRES;	
			else if((KEY_NUM&0x40)==0)return KEY2_PRES;
      else if((KEY_NUM&0x20)==0)return KEY3_PRES;
			}
			
	}else if((KEY_NUM&0xe0)==0xe0)key_up=1; 	 
 	return 0;// 无按键按下
}


void TEST_IMG(void)//自动播放画面的同时按键有效
{
	unsigned char f,i,dly;
dly=Auto_Delay/10;
		for(i=0;i<dly;i++)//此循环决定了延时长短
	{
		Delay(10);
		f=KEY_Scan();	
		
			if(f==KEY2_PRES)
		{
				at_jump=0;
				FM_short();
				lcd_show(12);		
				PCH=12;
			i=dly;
		}	
		
		if(f==KEY3_PRES)
		{
				at_jump=0;
				FM_short();
				lcd_show(11);		
					PCH=11;
			i=dly;
		}
		
			if(f==KEY1_PRES)
			{				
				switch(POWER_VOL)
				{
					case 0: Power_off(); break;
					case 1: Power_on(); at_jump=1;  break;												
					default: break;
				}
							i=dly;
			}
	}


}
//-----------------------OLED----------------------------

//初始化SSD1306					    
void OLED_Init(void)
{
 
  OLED_RST_Set();
	delay_ms(100);
	OLED_RST_Clr();
	delay_ms(100);
	OLED_RST_Set(); 

	OLED_WR_Byte(0xAE,OLED_CMD);//--turn off oled panel
	OLED_WR_Byte(0x00,OLED_CMD);//---set low column address
	OLED_WR_Byte(0x10,OLED_CMD);//---set high column address
	OLED_WR_Byte(0x40,OLED_CMD);//--set start line address  Set Mapping RAM Display Start Line (0x00~0x3F)
	OLED_WR_Byte(0x81,OLED_CMD);//--set contrast control register
	OLED_WR_Byte(0xCF,OLED_CMD); // Set SEG Output Current Brightness
	OLED_WR_Byte(0xA1,OLED_CMD);//--Set SEG/Column Mapping     0xa0左右反置 0xa1正常
	OLED_WR_Byte(0xC8,OLED_CMD);//Set COM/Row Scan Direction   0xc0上下反置 0xc8正常
	OLED_WR_Byte(0xA6,OLED_CMD);//--set normal display
	OLED_WR_Byte(0xA8,OLED_CMD);//--set multiplex ratio(1 to 64)
	OLED_WR_Byte(0x3f,OLED_CMD);//--1/64 duty
	OLED_WR_Byte(0xD3,OLED_CMD);//-set display offset	Shift Mapping RAM Counter (0x00~0x3F)
	OLED_WR_Byte(0x00,OLED_CMD);//-not offset
	OLED_WR_Byte(0xd5,OLED_CMD);//--set display clock divide ratio/oscillator frequency
	OLED_WR_Byte(0x80,OLED_CMD);//--set divide ratio, Set Clock as 100 Frames/Sec
	OLED_WR_Byte(0xD9,OLED_CMD);//--set pre-charge period
	OLED_WR_Byte(0xF1,OLED_CMD);//Set Pre-Charge as 15 Clocks & Discharge as 1 Clock
	OLED_WR_Byte(0xDA,OLED_CMD);//--set com pins hardware configuration
	OLED_WR_Byte(0x12,OLED_CMD);
	OLED_WR_Byte(0xDB,OLED_CMD);//--set vcomh
	OLED_WR_Byte(0x40,OLED_CMD);//Set VCOM Deselect Level
	OLED_WR_Byte(0x20,OLED_CMD);//-Set Page Addressing Mode (0x00/0x01/0x02)
	OLED_WR_Byte(0x02,OLED_CMD);//
	OLED_WR_Byte(0x8D,OLED_CMD);//--set Charge Pump enable/disable
	OLED_WR_Byte(0x14,OLED_CMD);//--set(0x10) disable
	OLED_WR_Byte(0xA4,OLED_CMD);// Disable Entire Display On (0xa4/0xa5)
	OLED_WR_Byte(0xA6,OLED_CMD);// Disable Inverse Display On (0xa6/a7) 
	OLED_WR_Byte(0xAF,OLED_CMD);//--turn on oled panel
	
	OLED_WR_Byte(0xAF,OLED_CMD); /*display ON*/ 
	OLED_Clear();
	OLED_Set_Pos(0,0); 	
}  


void OLED_WR_Byte(u8 dat,u8 cmd)
{	
	u8 i;			  
	if(cmd)
	  OLED_DC_Set();
	else 
	  OLED_DC_Clr();		  
	OLED_CS_Clr();
	for(i=0;i<8;i++)
	{			  
		OLED_SCLK_Clr();
		if(dat&0x80)
			{
		   OLED_SDIN_Set();
			}
else
		   OLED_SDIN_Clr();
				OLED_SCLK_Set();
		dat<<=1;   
	}				 		  
	OLED_CS_Set();
	OLED_DC_Set();   	  
} 





	void OLED_Set_Pos(unsigned char x, unsigned char y) 
{ 
	OLED_WR_Byte(0xb0+y,OLED_CMD);
	OLED_WR_Byte(((x&0xf0)>>4)|0x10,OLED_CMD);
	OLED_WR_Byte((x&0x0f)|0x01,OLED_CMD); 
}   	  
//开启OLED显示    
void OLED_Display_On(void)
{
	OLED_WR_Byte(0X8D,OLED_CMD);  //SET DCDC命令
	OLED_WR_Byte(0X14,OLED_CMD);  //DCDC ON
	OLED_WR_Byte(0XAF,OLED_CMD);  //DISPLAY ON
}
//关闭OLED显示     
void OLED_Display_Off(void)
{
	OLED_WR_Byte(0X8D,OLED_CMD);  //SET DCDC命令
	OLED_WR_Byte(0X10,OLED_CMD);  //DCDC OFF
	OLED_WR_Byte(0XAE,OLED_CMD);  //DISPLAY OFF
}		   			 
//清屏函数,清完屏,整个屏幕是黑色的!和没点亮一样!!!	  
void OLED_Clear(void)  
{  
	u8 i,n;		    
	for(i=0;i<8;i++)  
	{  
		OLED_WR_Byte (0xb0+i,OLED_CMD);    //设置页地址（0~7）
		OLED_WR_Byte (0x00,OLED_CMD);      //设置显示位置—列低地址
		OLED_WR_Byte (0x10,OLED_CMD);      //设置显示位置—列高地址   
		for(n=0;n<128;n++)OLED_WR_Byte(0,OLED_DATA); 
	} //更新显示
}

//在指定位置显示一个字符,包括部分字符
//x:0~127
//y:0~63
//mode:0,反白显示;1,正常显示				 
//size:选择字体 16/12 
void OLED_ShowChar(u8 x,u8 y,u8 chr)
{      	
	unsigned char c=0,i=0;	
		c=chr-' ';//得到偏移后的值			
		if(x>Max_Column-1){x=0;y=y+2;}
		if(SIZE ==16)
			{
			OLED_Set_Pos(x,y);	
			for(i=0;i<8;i++)
			OLED_WR_Byte(F8X16[c*16+i],OLED_DATA);
			OLED_Set_Pos(x,y+1);
			for(i=0;i<8;i++)
			OLED_WR_Byte(F8X16[c*16+i+8],OLED_DATA);
			}
			
//			else {	
//				OLED_Set_Pos(x,y+1);
//				for(i=0;i<6;i++)
//				OLED_WR_Byte(F6x8[c][i],OLED_DATA);
//				
//			}
			
}
//m^n函数
u32 oled_pow(u8 m,u8 n)
{
	u32 result=1;	 
	while(n--)result*=m;    
	return result;
}				  
//显示2个数字
//x,y :起点坐标	 
//len :数字的位数
//size:字体大小
//mode:模式	0,填充模式;1,叠加模式
//num:数值(0~4294967295);	 		  
void OLED_ShowNum(u8 x,u8 y,u32 num,u8 len,u8 size2)
{         	
	u8 t,temp;
	u8 enshow=0;						   
	for(t=0;t<len;t++)
	{
		temp=(num/oled_pow(10,len-t-1))%10;
		if(enshow==0&&t<(len-1))
		{
			if(temp==0)
			{
				OLED_ShowChar(x+(size2/2)*t,y,' ');
				continue;
			}else enshow=1; 
		 	 
		}
	 	OLED_ShowChar(x+(size2/2)*t,y,temp+'0'); 
	}
} 
//显示一个字符号串
void OLED_ShowString(u8 x,u8 y,u8 *chr)
{
	unsigned char j=0;
	while (chr[j]!='\0')
	{		OLED_ShowChar(x,y,chr[j]);
			x+=8;
		if(x>120){x=0;y+=2;}
			j++;
	}
}
//显示汉字
void OLED_ShowCHinese(u8 x,u8 y,u8 no)
{      			    
	u8 t,adder=0;
	OLED_Set_Pos(x,y);	
    for(t=0;t<16;t++)
		{
				OLED_WR_Byte(Hzk[2*no][t],OLED_DATA);
				adder+=1;
     }	
		OLED_Set_Pos(x,y+1);	
    for(t=0;t<16;t++)
			{	
				OLED_WR_Byte(Hzk[2*no+1][t],OLED_DATA);
				adder+=1;
      }					
}












//---------------------------------------------------------

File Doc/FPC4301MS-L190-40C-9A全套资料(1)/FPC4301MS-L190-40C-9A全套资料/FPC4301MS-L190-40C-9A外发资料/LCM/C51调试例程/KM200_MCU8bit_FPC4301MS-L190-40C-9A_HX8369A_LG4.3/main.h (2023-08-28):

#ifndef __MAIN_h__
#define __MAIN_h__

typedef  unsigned char   uint8;
typedef  signed char     int8;
typedef  unsigned int    uint16;
typedef  signed int	     int16;   
typedef  unsigned long	 uint32; 
typedef  signed long	 int32; 


//------------------------------------------------------
#define ROW  800		     	//480
#define COL  480          //320
//------------------------------------------------------
#define MCU               ///
//#define SPI               //

//------------------------------------------------------
#ifdef  MCU
#define MCU8bit         //根据实际需要选择，不要同时打开
//#define MCU16bit   	    //
#endif
//------------------------------------------------------
//------------------------------------------------------
#ifdef  SPI
//#define SPI_3W       //3线SPI  无 RS
 #define SPI_4W       //4线SPI  有 RS
#endif
//------------------------------------------------------
#define AUTO_PIC    1     //1：打开自动跑画面，0手动跑画面
#define Auto_Delay  800		//自动跑画面的延时，10ms步进
//------------------------------------------------------
#define PIC_T             //打开图片显示
//------------------------------------------------------
//  只能选择打开一张图片，否则报错
#define mugu            //显示小蘑菇图片
//#define shuiguo         //显示水果图片
//#define renwu            //显示人物图片
//------------------------------------------------------
#define  READ_REG         //打开读屏寄存器功能  
#define  IC_REG  0xF4    //需要读取的寄存器
#define  REG_NUM  4       //寄存器参数个数 ， 小屏只能显示7个数据，大于7的会省略不显示
//------------------------------------------------------
#define    vcom_adj    1
#define  vcom_Step     2   //调试步进
#define  vcom_default  50   //默认值


//---------------以下不要修改-------------------------------------------------------------------------------------------

#define DBH  P3			    
#define DBL  P0	


#define KEY1_PRES 	3	//电源开关
#define KEY2_PRES	  2	//上一步
#define KEY3_PRES	  1	//下一步
 
//LCM
sbit	CS0 = P1^3;
sbit	RST = P1^0;
sbit	RS  = P1^4;
sbit	WR0 = P1^2;
sbit	RD0 = P1^1;



sbit	SPI_DI = P0^2;
sbit	SPI_CLK = P0^0;
sbit	SPI_CS = P0^5;		 
sbit	SPI_RS = P0^6;
sbit	SPI_RES = P0^4;



sbit	IOVCC_EN = P2^3;
sbit	VCI_EN   = P2^4;
sbit	BL_EN    = P2^5;
sbit	MTP_EN   = P2^6;
sbit	FMQ      = P2^2;

#define RED    0xF800		 //定义颜色常量 
#define GREEN  0x07E0
#define BLUE   0x001F
#define WHITE  0xFFFF
#define BLACK  0x0000
#define GRAY   0xEF5D	     //0x2410
#define GRAY75 0x39E7 
#define GRAY50 0x7BEF	
#define GRAY25 0xADB5	

//-----------OLED_--------------------------------------

#define  u8 unsigned char 
#define  u32 unsigned int 
#define OLED_CMD  0	//写命令
#define OLED_DATA 1	//写数据
#define OLED_MODE 0

sbit OLED_CS=P1^5; //片选
sbit OLED_RST =P1^7;//复位
sbit OLED_DC =P1^6;//数据/命令控制
sbit OLED_SCL=P2^1;//时钟 D0（SCLK?
sbit OLED_SDIN=P2^0;//D1（MOSI） 数据

#define delay_ms  Delay

#define SIZE 16
#define XLevelL		0x02
#define XLevelH		0x10
#define Max_Column	128
#define Max_Row		64
#define	Brightness	0xFF 
#define X_WIDTH 	128
#define Y_WIDTH 	64	 

#define OLED_CS_Clr()  OLED_CS=0
#define OLED_CS_Set()  OLED_CS=1

#define OLED_RST_Clr() OLED_RST=0
#define OLED_RST_Set() OLED_RST=1

#define OLED_DC_Clr() OLED_DC=0
#define OLED_DC_Set() OLED_DC=1

#define OLED_SCLK_Clr() OLED_SCL=0
#define OLED_SCLK_Set() OLED_SCL=1

#define OLED_SDIN_Clr() OLED_SDIN=0
#define OLED_SDIN_Set() OLED_SDIN=1;



void OLED_WR_Byte(u8 dat,u8 cmd);	    
void OLED_Display_On(void);
void OLED_Display_Off(void);	   							   		    
void OLED_Init(void);
void OLED_Clear(void);
void OLED_DrawPoint(u8 x,u8 y,u8 t);
void OLED_Fill(u8 x1,u8 y1,u8 x2,u8 y2,u8 dot);
void OLED_ShowChar(u8 x,u8 y,u8 chr);
void OLED_ShowNum(u8 x,u8 y,u32 num,u8 len,u8 size2);
void OLED_ShowString(u8 x,u8 y, u8 *p);	 
void OLED_Set_Pos(unsigned char x, unsigned char y);
void OLED_ShowCHinese(u8 x,u8 y,u8 no);


//------------------------------------------------------
void  Delay(unsigned int dly);
void  WaitKey(void);
unsigned char KEY_Scan(void);
void  Suspend_Device(void);
void  Devices_Init(void);
void  MCU_Init(void); 
void FM_short(void);
void FM_Long(void);
void TEST_IMG(void);




#endif

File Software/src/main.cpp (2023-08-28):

#include "head.h"
const char *ssid = "vivoS12";
const char *password = "7bsgbsg7";
void setup()
{
  Serial.begin(115200); /* prepare for possible serial debug */

  lv_init();

  tft.begin();        /* TFT init */
  tft.setRotation(3); /* Landscape orientation, flipped */

  lv_port_disp_init();  // 显示设备初始化
  lv_port_indev_init(); // 初始化输入设备，这里是触摸屏或者拨动按键
  WiFi.begin(ssid, password);
  pinMode(music_pin,OUTPUT);
  gui_init();
}

void loop()
{
  lv_timer_handler(); /* let the GUI do its work */
  delay(5);
  // LV_LOG_USER("slider_value=%d",slider_value);
}
